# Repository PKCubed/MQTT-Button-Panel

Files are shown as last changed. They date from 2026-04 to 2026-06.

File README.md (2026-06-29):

# MQTT-Button-Panel

A panel of four, customizable, RGB-backlit buttons designed for use with Home Assistant and communication over MQTT via WiFi and Ethernet.

PXL_20260501_205123144 RAW-01 MP COVER

# Setup Steps (Work in Progress)
- Setup MQTT broker
- Add command router automation to HA
- Configure a button panel with its web interface
  - Find it's IP address by entering the menu (pressing both small buttons at the same time)
  - Set the MQTT broker IP address
  - Configure buttons with entity IDs
- Add button panel to HA
- Create automations to control systems with the button panel entities
  - Use [this blueprint](https://gist.github.com/PKCubed/5fed5823f06fd57056f4231d421e1b52) to link the button panel entities to switches

## Hardware

This design is centered around a WT32-ETH01 development board. This is an ESP32 with a LAN8720 Ethernet transceiver allowing for both WiFi and Ethernet connectivity.
On the circuit board are placed the 4 main buttons and two bank/menu buttons. Each button has a WS2812b addressable RGB led placed next to it. The front side of the board also holds the 16x2 character LCD.
The back side of the PCB holds the WT32-ETH01. To program the ESP32, the board is populated with a CP2102 USB to UART converter IC. This allows us to easily program the ESP32 with the USB C connection.
To interface with the character LCD and buttons, two PCF8574 I2C IO expanders are placed on the board. One of which is used for the character LCD while the other is used to read input from the 6 buttons.

## 3D Printed Case

Click [here](/cad/README.md) for detailed 3D printing instructions.

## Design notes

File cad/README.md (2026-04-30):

# Printing Instructions

## Buttons



* ### Transparent Part

PXL_20260430_143414308 RAW-01 MP COVER

\
Set infill to solid (100% density) and choose a pattern you like. Concentric infill gives a nice transparency. Choosing the largest layer height seems to give the best transparency. Below are the settings I used:
| Setting | Value |
| :--- | :--- |
| Layer height | 0.28mm |
| Wall loops | 1 |
| Top surface pattern | Concentric |
| Bottom surface pattern | Concentric |
| Internal solid infill pattern | Concentric |
| Infill pattern | Concentric |
| Infill density | 100% |

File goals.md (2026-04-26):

# Functional Requirements Specification: Church Automation Button Panel

## 1. Project Overview
This document outlines the functional goals and operational requirements for a network-connected button panel, designed primarily for church lighting and systems automation. The panel serves as an interactive MQTT client, sending commands to Home Assistant, which acts as the central automation hub. Key features include dynamic button mapping via "fader-style" banks, capacitive touch previewing, RGB status indication, seamless network failover, and comprehensive web-based configuration.

## 2. Hardware Overview
* **Processing & Connectivity:** WT32-ETH01 (Provides both Ethernet and Wi-Fi capabilities).
* **Programming Interface:** Custom PCB featuring a CP2102 for USB-C programming and debugging.
* **Display:** 16x2 Character LCD for local feedback and menus.
* **Physical Controls:** * 4x Main Action Buttons.
    * 2x Bank Control Buttons (Up / Down).
* **Sensory Inputs:** 6x capacitive touch rings (one surrounding each physical button).
* **Visual Indicators:** 6x Addressable RGB LEDs located beneath each button.

## 3. Functional Requirements

### 3.1. Bank and Button Management
* **Bank Shifting:** The panel must support multiple "banks" of button layouts, similar to a digital mixing console. The Bank Up and Bank Down buttons shift the logical assignment of the 4 main physical buttons to a new set of functions.
* **Configurable Button Types:** Each logical button (e.g., Button 2 on Bank 3) must be individually configurable to behave as:
    * `Toggle / On-Off`: Alternates between two states per press.
    * `Momentary`: Active only while physically held down.
    * `Radio / Scene`: Pressing the button activates it and deactivates any other buttons assigned to the same "radio group."
* **State Synchronization:** The panel must track the state of each button locally to control its LED, while simultaneously listening for external state changes broadcasted via MQTT (ensuring two-way sync with Home Assistant).

### 3.2. Capacitive Touch "Preview" Mode
* **Touch to Preview:** Touching the capacitive ring around any button *without physically depressing it* must trigger a preview action.
* **Display Feedback:** Upon touch detection, the 16x2 LCD must immediately display the configured name and intended function of that specific button.
* **Auto-Revert:** When the user removes their finger from the capacitive ring, the LCD must automatically revert to its default idle view.

### 3.3. LCD Display Behavior
* **Idle State:** * Top Line: Displays the custom Panel Name or the currently active Bank Name.
    * Bottom Line: Displays network status, active IP address, or a general system summary.
* **Preview State (During Touch):**
    * Top Line: "Button: [Assigned Button Name]"
    * Bottom Line: "Action: [Assigned Function/Current State]"
* **Menu State:** Displays navigable settings when the local menu is activated (see Section 3.7).

### 3.4. LED Status Management
* **State Indication:** The RGB LED beneath each button reflects its current state.
* **Customization:** The colors for "ON" and "OFF" states must be user-configurable per button via the Web UI. The system defaults to Green for ON and Red for OFF.
* **Bank Transition Feedback:** The LEDs under the Bank Up/Down buttons should provide visual feedback (e.g., a brief flash) to confirm a successful bank change, or indicate if the user has reached the highest/lowest available bank.

### 3.5. Network Connectivity and Failover
* **Primary Link:** Hardwired Ethernet.
* **Secondary Link:** Wi-Fi.
* **Automatic Failover:** The system must actively monitor the Ethernet connection. If the physical link drops or the connection to the MQTT broker is lost, the panel must seamlessly and automatically switch to the pre-configured Wi-Fi network to maintain functionality.
* **IP Management:** The panel must support both DHCP (default) and Static IP addressing.

### 3.6. MQTT Integration
* **Standardized Communication:** All actions and state changes are communicated to the Home Assistant broker via MQTT.
* **Configurable Topics:** Base topic structures and individual button labels must be entirely customizable via the Web UI to fit the user's existing Home Assistant naming conventions.
* **Standardized Payloads:** The panel should use standard, easily parseable payloads (e.g., simple strings like "ON", "OFF" or basic JSON).

### 3.7. Local Device Menu
* **Activation:** The user can access a local configuration menu directly on the panel by pressing and holding both the Bank Up and Bank Down buttons simultaneously.
* **Navigation:** The Bank Up/Down buttons are used to scroll through menu items, while specific main buttons act as "Select" and "Back/Exit".
* **Menu Capabilities:**
    * **Network Diagnostics:** View active interface (ETH vs. Wi-Fi), IP Address, and MAC Address.
    * **IP Configuration:** Toggle between DHCP and Static IP modes, and manually alter a static IP address directly from the panel.
    * **System Control:** Trigger a device reboot or initiate a full factory reset.

### 3.8. Web Configuration Interface
* **Accessibility:** The panel must host a local web server accessible via standard web browsers.
* **Global Settings:** Configure Panel Name, Max Number of Banks, and MQTT Broker details (IP, Port, Username, Password).
* **Network Settings:** Input Wi-Fi credentials and define IP configurations.
* **Button Matrix Setup:** A comprehensive interface to define the behavior for every button on every bank. This includes:
    * The Button's Display Name (for the LCD).
    * The specific MQTT label/topic.
    * The Button Type (Toggle, Momentary, Scene Group).
    * Custom RGB HEX codes for ON and OFF states.
* **Persistence:** All settings configured in the web interface must be saved securely to non-volatile memory so they survive reboots and power cycles.

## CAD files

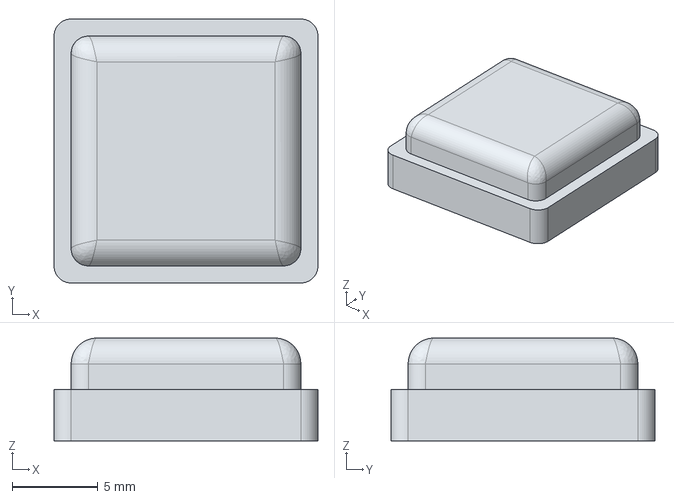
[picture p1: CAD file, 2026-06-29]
cad/Small Button.step
15.4 x 15.4 x 6.00 mm

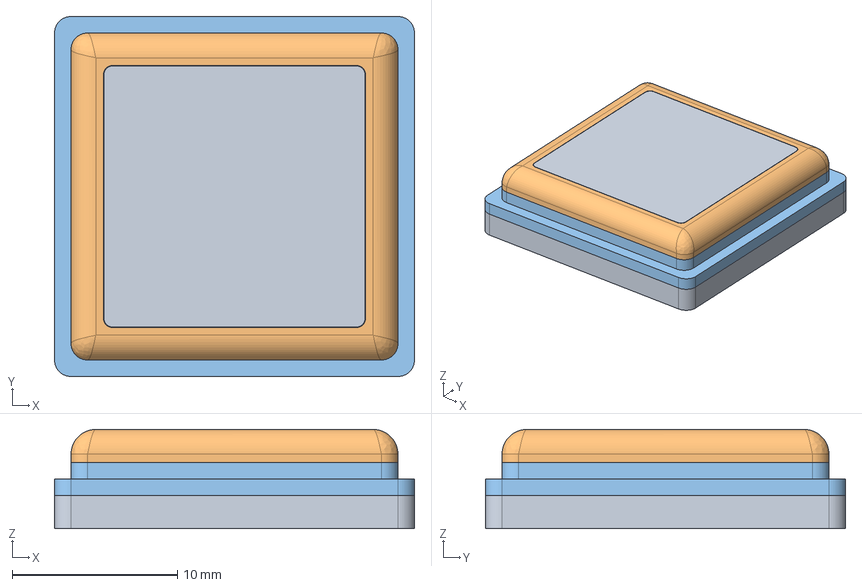
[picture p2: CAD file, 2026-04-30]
cad/4-Button Panel Buttons.FCStd
21.8 x 21.8 x 6.00 mm
Large Transparent
Large-Touch
Large Black

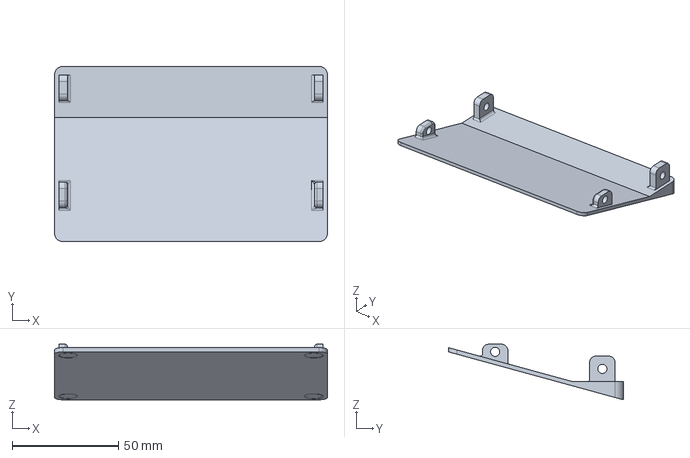
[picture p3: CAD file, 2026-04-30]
cad/4-Button Panel Case v1.3.FCStd
128.4 x 82.4 x 26.2 mm

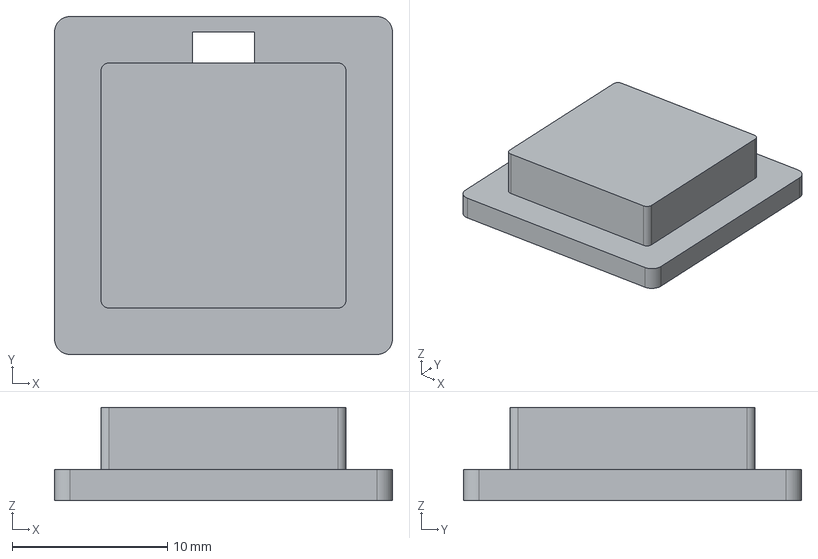
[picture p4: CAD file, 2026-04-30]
cad/Large Button (Transparent).step
21.8 x 21.8 x 6.00 mm

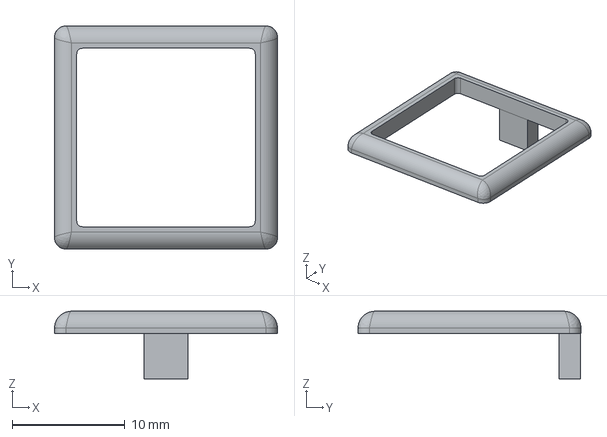
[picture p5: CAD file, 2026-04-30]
cad/Large Button (Conductive).step
19.8 x 19.8 x 6.00 mm

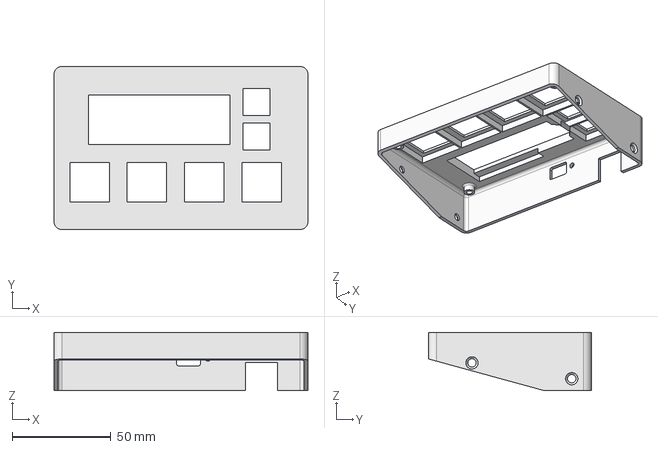
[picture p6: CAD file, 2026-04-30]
cad/Case Front v1.3.step
128.4 x 82.4 x 29.4 mm

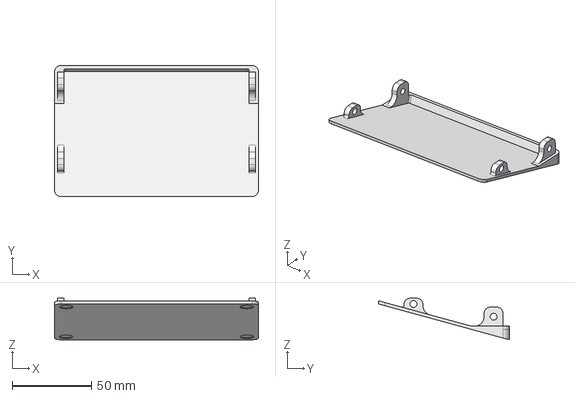
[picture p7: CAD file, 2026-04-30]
cad/Case Back v1.3.step
128.4 x 82.4 x 26.2 mm

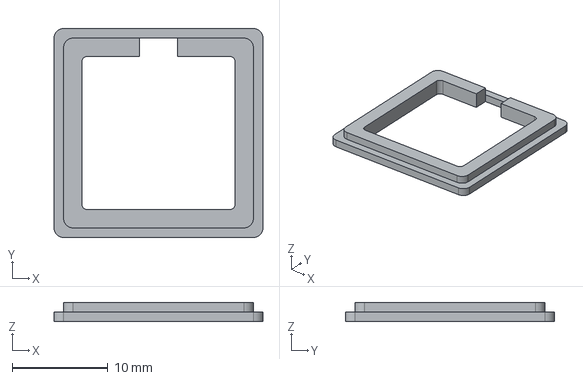
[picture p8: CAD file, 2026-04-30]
cad/Large Button (Black).step
21.8 x 21.8 x 2.00 mm

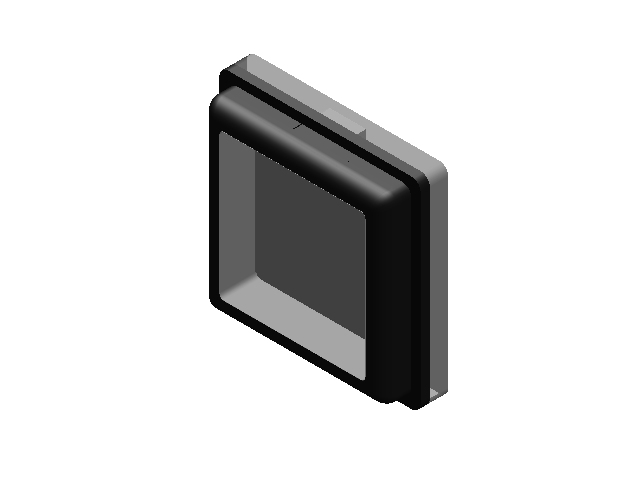
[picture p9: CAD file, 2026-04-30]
cad/Large Button.SLDASM
Large Button (Black)
Large Button (Conductive)
Large Button (Transparent)

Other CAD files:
cad/Case Back v1.3.3MF
cad/Case Back v1.3.SLDPRT
cad/Case Front v1.3.3MF
cad/Case Front v1.3.SLDPRT
cad/Large Button (Black).SLDPRT
cad/Large Button (Conductive).SLDPRT
cad/Large Button (Transparent).SLDPRT

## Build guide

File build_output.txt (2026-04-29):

Processing wt32-eth01 (platform: espressif32; board: wt32-eth01; framework: espidf)
--------------------------------------------------------------------------------
Verbose mode can be enabled via `-v, --verbose` option
CONFIGURATION: https://docs.platformio.org/page/boards/espressif32/wt32-eth01.html
PLATFORM: Espressif 32 (6.11.0) > Wireless-Tag WT32-ETH01 Ethernet Module
HARDWARE: ESP32 240MHz, 320KB RAM, 4MB Flash
DEBUG: Current (cmsis-dap) External (cmsis-dap, esp-bridge, esp-prog, iot-bus-jtag, jlink, minimodule, olimex-arm-usb-ocd, olimex-arm-usb-ocd-h, olimex-arm-usb-tiny-h, olimex-jtag-tiny, tumpa)
PACKAGES: 
 - framework-espidf @ 3.50401.0 (5.4.1) 
 - tool-cmake @ 3.16.4 
 - tool-esp-rom-elfs @ 0.0.1+20241011 
 - tool-esptoolpy @ 1.40501.0 (4.5.1) 
 - tool-idf @ 1.0.1 
 - tool-mconf @ 1.4060000.20190628 (406.0.0) 
 - tool-ninja @ 1.9.0 
 - tool-riscv32-esp-elf-gdb @ 11.2.0+20220823 
 - tool-xtensa-esp-elf-gdb @ 11.2.0+20230208 
 - toolchain-esp32ulp @ 1.23800.240113 (2.38.0) 
 - toolchain-xtensa-esp-elf @ 14.2.0+20241119
Reading CMake configuration...
LDF: Library Dependency Finder -> https://bit.ly/configure-pio-ldf
LDF Modes: Finder ~ chain, Compatibility ~ soft
Found 0 compatible libraries
Scanning dependencies...
No dependencies
Building in release mode
Linking .pio\build\wt32-eth01\firmware.elf
Retrieving maximum program size .pio\build\wt32-eth01\firmware.elf
Checking size .pio\build\wt32-eth01\firmware.elf
Advanced Memory Usage is available via "PlatformIO Home > Project Inspect"
RAM:   [=         ]  13.0% (used 42624 bytes from 327680 bytes)
Flash: [===       ]  26.3% (used 1067400 bytes from 4063232 bytes)
Building .pio\build\wt32-eth01\firmware.bin
esptool.py v4.5.1
Creating esp32 image...
Merged 2 ELF sections
Successfully created esp32 image.
========================= [SUCCESS] Took 12.99 seconds =========================

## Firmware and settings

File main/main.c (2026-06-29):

#include <stdio.h>
#include <string.h>
#include <ctype.h>

#include "driver/gpio.h"
#include "driver/i2c.h"
#include "driver/rmt.h"
#include "driver/touch_pad.h"
#include "esp_eth.h"
#include "esp_wifi.h"
#include "esp_event.h"
#include "esp_log.h"
#include "esp_netif.h"
#include "esp_netif_defaults.h"
#include "esp_timer.h"
#include "freertos/FreeRTOS.h"
#include "freertos/task.h"
#include "freertos/queue.h"
#include "freertos/semphr.h"
#include "nvs_flash.h"

#include "esp_http_server.h"
#include "nvs.h"
#include "cJSON.h"
#include "web_assets.h"

#include "mqtt_client.h"
#include "esp_system.h"
static esp_mqtt_client_handle_t s_mqtt_client = NULL;

#define ARRAY_LEN(x) (sizeof(x) / sizeof((x)[0]))
static const char *TAG = "panel_main";

/* -------------------------------------------------------------------------- */
/* Hardware mapping                                                           */
/*                                                                            */
/* These values describe the board wiring. Keeping them centralized makes it  */
/* easier to change hardware without chasing pin numbers through the rest of  */
/* the code.                                                                  */
/* -------------------------------------------------------------------------- */
#define ETH_PHY_ADDR 1
#define ETH_PHY_RST_GPIO -1
#define ETH_MDC_GPIO 23
#define ETH_MDIO_GPIO 18
#define ETH_PHY_POWER_GPIO 16

#define I2C_PORT I2C_NUM_0
#define I2C_SDA GPIO_NUM_14
#define I2C_SCL GPIO_NUM_5
#define I2C_FREQ_HZ 100000

#define PCF_LCD_ADDR 0x27
#define PCF_BUTTON_ADDR 0x26

#define LCD_PIN_EN 0x04
#define LCD_PIN_RW 0x02
#define LCD_PIN_RS 0x01
#define LCD_PIN_BL 0x08

#define BUTTON_COUNT 6
static const uint8_t k_button_pcf_bits[BUTTON_COUNT] = {5, 4, 3, 2, 1, 0};

static const touch_pad_t k_touch_channels[BUTTON_COUNT] = {
    TOUCH_PAD_NUM0, TOUCH_PAD_NUM3, TOUCH_PAD_NUM2, 
    TOUCH_PAD_NUM5, TOUCH_PAD_NUM9, TOUCH_PAD_NUM8,
};

#define LED_COUNT 6
#define LED_PIN GPIO_NUM_17
#define WS2812_RMT_CHANNEL RMT_CHANNEL_0
#define WS2812_RMT_CLK_DIV 2
#define WS2812_T0H_TICKS 14
#define WS2812_T0L_TICKS 32
#define WS2812_T1H_TICKS 28
#define WS2812_T1L_TICKS 24
#define WS2812_RESET_TICKS 2400

/* -------------------------------------------------------------------------- */
/* Panel configuration model                                                  */
/*                                                                            */
/* The runtime UI is driven by a small in-memory description of the panel:    */
/* banks, buttons, MQTT topics, and LED colors.                               */
/* -------------------------------------------------------------------------- */
#define MAX_BANKS 8
#define MAIN_BTN_COUNT 4
#define BTN_BANK_DOWN 4
#define BTN_BANK_UP 5
#define CONFIG_FORMAT_VERSION 2

typedef enum { BTN_TYPE_TOGGLE, BTN_TYPE_MOMENTARY, BTN_TYPE_RADIO } btn_type_t;

typedef struct {
    char display_name[17];
    char entity_id[64];
    btn_type_t type;
    uint8_t color_on[3];  // RGB
    uint8_t color_off[3]; // RGB
    uint8_t radio_group;  // 0 means no group
} button_config_t;

typedef struct {
    char bank_name[17];
    button_config_t buttons[MAIN_BTN_COUNT];
} bank_config_t;

typedef struct {
    char panel_name[17];
    uint8_t num_banks;
    bank_config_t banks[MAX_BANKS];
} system_config_t;

typedef struct {
    char broker_ip[32];
    char port[8];      // Kept as string for easier HTML form parsing
    char username[32];
    char password[64];
} mqtt_config_t;

typedef struct {
    char ssid[33];           // WiFi SSID (max 32 chars)
    char password[64];       // WiFi password
    bool use_dhcp;           // true = DHCP, false = static IP
    char static_ip[16];      // Static IP address (e.g., "192.168.1.50")
    char static_netmask[16]; // Netmask (e.g., "255.255.255.0")
    char static_gateway[16]; // Gateway (e.g., "192.168.1.1")
} app_wifi_config_t;

/* Default MQTT settings are loaded into RAM first, then overwritten from     */
/* NVS if the user has already saved values from the web UI.                  */
static mqtt_config_t s_mqtt_config = {
    .broker_ip = "192.168.1.100",
    .port = "1883",
    .username = "",
    .password = ""
};

/* Default WiFi settings */
static app_wifi_config_t s_wifi_config = {
    .ssid = "YOUR_SSID",
    .password = "YOUR_PASS",
    .use_dhcp = true,
    .static_ip = "192.168.1.100",
    .static_netmask = "255.255.255.0",
    .static_gateway = "192.168.1.1"
};

/* -------------------------------------------------------------------------- */
/* Runtime state                                                              */
/*                                                                            */
/* These globals are intentionally split between persistent configuration     */
/* and live state. The hardware task only reports changes; the logic task      */
/* decides what those changes mean for the UI and MQTT state.                 */
/* -------------------------------------------------------------------------- */
static system_config_t s_config;
static uint8_t s_current_bank = 0;
static bool s_btn_states[MAX_BANKS][MAIN_BTN_COUNT] = {false}; // Logical states (ON/OFF)
static bool s_in_menu = false;
static int s_menu_index = 0;
static const char *s_menu_items[] = { "Active IP", "MQTT Broker IP", "System Uptime" };
static const int s_menu_items_count = sizeof(s_menu_items) / sizeof(s_menu_items[0]);
static bool s_in_submenu = false;
static char s_active_ip[16] = "0.0.0.0";
static int64_t s_boot_time_ms = 0;
static int64_t s_mqtt_connect_time_ms = 0;
static bool s_mqtt_connected = false;
/* Startup animation keeps running until boot is fully complete.              */
static bool s_startup_complete = false;
static bool s_bank_btns_held[2] = {false, false};
static bool s_ignore_bank_release[2] = {false, false};

/* Connection flags let the UI decide whether to show online/offline cues     */
/* without needing to query the networking stack repeatedly.                  */
static bool s_eth_connected = false;
static bool s_wifi_connected = false;

/* Input events are funneled through a queue so the tasks stay decoupled.     */
static QueueHandle_t s_btn_event_queue;

typedef enum { EVT_BTN_PRESSED, EVT_BTN_RELEASED, EVT_TOUCH_START, EVT_TOUCH_END, EVT_MQTT_SYNC } event_type_t;
typedef struct {
    event_type_t type;
    uint8_t btn_idx;
} input_event_t;


/* RMT frame buffer used to encode one WS2812 LED update.                     */
static rmt_item32_t s_led_items[(LED_COUNT * 24) + 1];
static bool s_eth_link = false;
static bool s_eth_has_ip = false;

/* Touch sensing is based on a baseline captured at boot.                    */
static uint16_t s_touch_baseline[BUTTON_COUNT] = {0};
static bool s_touch_ready = false;

static uint8_t s_button_state = 0xFF;
static uint8_t s_button_last_state = 0xFF;
static int64_t s_button_last_change_ms[BUTTON_COUNT] = {0};

/* Cache the last LCD output so we can avoid sending unchanged text over I2C. */
static char s_lcd_last_line1[17] = {0};
static char s_lcd_last_line2[17] = {0};
static SemaphoreHandle_t s_i2c_mutex = NULL;
static SemaphoreHandle_t s_lcd_mutex = NULL;

/* Keep configuration within safe bounds even if NVS data is old/corrupt. */
static void sanitize_config(void)
{
    if (s_config.num_banks < 1 || s_config.num_banks > MAX_BANKS) {
        s_config.num_banks = 1;
    }

    s_config.panel_name[sizeof(s_config.panel_name) - 1] = '\0';

    for (int b = 0; b < MAX_BANKS; ++b) {
        s_config.banks[b].bank_name[sizeof(s_config.banks[b].bank_name) - 1] = '\0';
        for (int i = 0; i < MAIN_BTN_COUNT; ++i) {
            button_config_t *btn = &s_config.banks[b].buttons[i];
            btn->display_name[sizeof(btn->display_name) - 1] = '\0';
            btn->entity_id[sizeof(btn->entity_id) - 1] = '\0';
            size_t topic_len = strnlen(btn->entity_id, sizeof(btn->entity_id));
            while (topic_len > 0) {
                unsigned char last = (unsigned char)btn->entity_id[topic_len - 1];
                if (last != '/' && !isspace(last)) {
                    break;
                }
                btn->entity_id[topic_len - 1] = '\0';
                topic_len--;
            }
            if (btn->type < BTN_TYPE_TOGGLE || btn->type > BTN_TYPE_RADIO) {
                btn->type = BTN_TYPE_TOGGLE;
            }
        }
    }

    if (s_current_bank >= s_config.num_banks) {
        s_current_bank = 0;
    }
}

/* Queue-based redraw helper. MQTT callbacks run outside the logic task, so   */
/* they request a refresh indirectly instead of touching UI state directly.   */
static void request_ui_refresh(void)
{
    if (s_btn_event_queue != NULL) {
        input_event_t sync_evt = {
            .type = EVT_MQTT_SYNC,
            .btn_idx = 0xFF,
        };
        xQueueSend(s_btn_event_queue, &sync_evt, 0);
    }
}


/* Keep all timing math in milliseconds for readability.                     */
static int64_t now_ms(void)
{
    return esp_timer_get_time() / 1000;
}

static void build_mqtt_topic(char *dst, size_t dst_size, const char *base_topic, const char *suffix)
{
    if (dst_size == 0) {
        return;
    }

    dst[0] = '\0';

    if (!base_topic || !suffix) {
        return;
    }

    size_t base_len = strnlen(base_topic, dst_size - 1);
    while (base_len > 0) {
        unsigned char last = (unsigned char)base_topic[base_len - 1];
        if (last != '/' && !isspace(last)) {
            break;
        }
        base_len--;
    }

    if (base_len == 0) {
        return;
    }

    snprintf(dst, dst_size, "%.*s/%s", (int)base_len, base_topic, suffix);
}

static void build_panel_mqtt_topic(char *dst, size_t dst_size, const char *entity_id, const char *suffix)
{
    if (dst_size == 0) {
        return;
    }

    dst[0] = '\0';

    if (!entity_id || !suffix) {
        return;
    }

    char base_topic[96];
    if (strncmp(entity_id, "panels/", 7) == 0) {
        snprintf(base_topic, sizeof(base_topic), "%s", entity_id);
    } else if (strncmp(entity_id, "panels-", 7) == 0) {
        snprintf(base_topic, sizeof(base_topic), "panels/%s", entity_id + 7);
    } else {
        snprintf(base_topic, sizeof(base_topic), "panels/%s", entity_id);
    }

    build_mqtt_topic(dst, dst_size, base_topic, suffix);
}

static void sanitize_discovery_id(char *dst, size_t dst_size, const char *src, const char *fallback)
{
    if (dst_size == 0) {
        return;
    }

    dst[0] = '\0';
    size_t out = 0;

    if (src != NULL) {
        for (size_t i = 0; src[i] != '\0' && out < dst_size - 1; ++i) {
            unsigned char ch = (unsigned char)src[i];
            if (isalnum(ch)) {
                dst[out++] = (char)tolower(ch);
            } else if (ch == '/' || ch == '-' || ch == ' ' || ch == '.') {
                dst[out++] = '_';
            } else if (ch == '_') {
                dst[out++] = '_';
            }
        }
    }

    if (out == 0 && fallback != NULL) {
        for (size_t i = 0; fallback[i] != '\0' && out < dst_size - 1; ++i) {
            unsigned char ch = (unsigned char)fallback[i];
            if (isalnum(ch)) {
                dst[out++] = (char)tolower(ch);
            } else if (ch == '/' || ch == '-' || ch == ' ' || ch == '.') {
                dst[out++] = '_';
            }
        }
    }

    dst[out] = '\0';
}

static void publish_button_discovery(uint8_t bank, uint8_t btn)
{
    if (!s_mqtt_client || !s_mqtt_connected) {
        return;
    }

    char legacy_device_id[48];
    sanitize_discovery_id(legacy_device_id, sizeof(legacy_device_id), s_config.panel_name, "mqtt_button_panel");
    if (legacy_device_id[0] == '\0') {
        snprintf(legacy_device_id, sizeof(legacy_device_id), "%s", "mqtt_button_panel");
    }

    char legacy_object_id[96];
    char legacy_discovery_topic[256];
    snprintf(legacy_object_id, sizeof(legacy_object_id), "%s_bank_%02u_button_%02u", legacy_device_id, (unsigned)(bank + 1), (unsigned)(btn + 1));
    snprintf(legacy_discovery_topic, sizeof(legacy_discovery_topic), "homeassistant/switch/%s/%s/config", legacy_device_id, legacy_object_id);

    esp_mqtt_client_publish(s_mqtt_client, legacy_discovery_topic, "", 0, 1, 1);

    char topic_id[96];
    char unique_id[192];
    char discovery_topic[256];

    const button_config_t *cfg = &s_config.banks[bank].buttons[btn];
    if (bank >= s_config.num_banks || cfg->entity_id[0] == '\0') {
        return;
    }

    sanitize_discovery_id(topic_id, sizeof(topic_id), cfg->entity_id, "button");
    if (topic_id[0] == '\0') {
        return;
    }

    snprintf(unique_id, sizeof(unique_id), "%s", topic_id);
    snprintf(discovery_topic, sizeof(discovery_topic), "homeassistant/switch/%s/config", topic_id);

     char state_topic[96];
     char command_topic[96];
     char ui_command_topic[96];
     build_panel_mqtt_topic(state_topic, sizeof(state_topic), cfg->entity_id, "state");
     build_panel_mqtt_topic(command_topic, sizeof(command_topic), cfg->entity_id, "command");
     /* Advertise a harmless UI command topic so Home Assistant accepts the discovery
         but ensure it won't be used by panels or the automation. This prevents HA
         from publishing to the real "command" topic that panels use. */
     build_panel_mqtt_topic(ui_command_topic, sizeof(ui_command_topic), cfg->entity_id, "ui_command");

    cJSON *root = cJSON_CreateObject();
    if (!root) {
        return;
    }

     cJSON_AddStringToObject(root, "name", cfg->display_name[0] ? cfg->display_name : topic_id);
     cJSON_AddStringToObject(root, "unique_id", unique_id);
     cJSON_AddStringToObject(root, "object_id", topic_id);
     /* Advertise a UI command topic that HA will publish to when toggled in the
         UI. Panels and the automation ignore this topic; the automation listens
         only to the canonical "command" topic published by panels. */
     //cJSON_AddStringToObject(root, "command_topic", ui_command_topic);
     cJSON_AddStringToObject(root, "command_topic", state_topic);
     cJSON_AddStringToObject(root, "state_topic", state_topic);
     cJSON_AddStringToObject(root, "payload_on", "ON");
     cJSON_AddStringToObject(root, "payload_off", "OFF");

    char *payload = cJSON_PrintUnformatted(root);
    if (payload != NULL) {
        esp_mqtt_client_publish(s_mqtt_client, discovery_topic, payload, 0, 1, 1);
        ESP_LOGI(TAG, "MQTT DISCOVERY: %s", discovery_topic);
        cJSON_free(payload);
    }

    cJSON_Delete(root);
}

static void clear_button_discovery_by_entity_id(const char *entity_id)
{
    if (!s_mqtt_client || !s_mqtt_connected || entity_id == NULL || entity_id[0] == '\0') {
        return;
    }

    char topic_id[96];
    char discovery_topic[256];
    sanitize_discovery_id(topic_id, sizeof(topic_id), entity_id, "button");
    if (topic_id[0] == '\0') {
        return;
    }

    snprintf(discovery_topic, sizeof(discovery_topic), "homeassistant/switch/%s/config", topic_id);
    esp_mqtt_client_publish(s_mqtt_client, discovery_topic, "", 0, 1, 1);
    ESP_LOGI(TAG, "MQTT DISCOVERY CLEAR: %s", discovery_topic);
}

static void publish_mqtt_discovery(void)
{
    if (!s_mqtt_client || !s_mqtt_connected) {
        return;
    }

    for (uint8_t b = 0; b < MAX_BANKS; ++b) {
        for (uint8_t i = 0; i < MAIN_BTN_COUNT; ++i) {
            publish_button_discovery(b, i);
        }
    }
}

static void subscribe_all_state_topics(const system_config_t *cfg)
{
    if (!s_mqtt_client || cfg == NULL) {
        return;
    }

    for (int b = 0; b < cfg->num_banks; b++) {
        for (int i = 0; i < MAIN_BTN_COUNT; i++) {
            char sub_topic[80];
            build_panel_mqtt_topic(sub_topic, sizeof(sub_topic), cfg->banks[b].buttons[i].entity_id, "state");
            esp_mqtt_client_subscribe(s_mqtt_client, sub_topic, 1);
            ESP_LOGI(TAG, "Subscribed to: %s", sub_topic);
        }
    }
}
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
void app_main(void)
{
    s_boot_time_ms = now_ms();
    // 1. Initialize NVS (Required for Wi-Fi and later web settings)
    esp_err_t ret = nvs_flash_init();
    if (ret == ESP_ERR_NVS_NO_FREE_PAGES || ret == ESP_ERR_NVS_NEW_VERSION_FOUND) {
      ESP_ERROR_CHECK(nvs_flash_erase());
      ret = nvs_flash_init();
    }
    ESP_ERROR_CHECK(ret);

    load_default_config();
    load_settings_nvs(); // Saved settings override the baked-in defaults.
    load_full_config_nvs(); // Load any saved full system config

    s_btn_event_queue = xQueueCreate(20, sizeof(input_event_t));

    ESP_ERROR_CHECK(esp_netif_init());
    ESP_ERROR_CHECK(esp_event_loop_create_default());

    // 2. Initialize Hardware
    // Bring up peripherals before networking so the splash screen can appear
    // immediately while the transport stack is still starting.
    i2c_init();       
    lcd_init();
    buttons_init();
    touch_init_all();
    ws2812_init();

    s_startup_complete = false;
    // The startup task keeps animating in the background until boot completes.
    xTaskCreate(startup_task, "startup_ui", 3072, NULL, 6, NULL);
    
    // 3. Initialize Network Failover
    init_network_failover();

    // 4. Create Tasks
    xTaskCreate(hardware_task, "hw_poll", 4096, NULL, 5, NULL);
    
    // 5. Start Web Server
    start_webserver();

    s_startup_complete = true;

    xTaskCreate(logic_task, "app_logic", 4096, NULL, 4, NULL);
    
    update_system_ui(-1);

    ESP_LOGI(TAG, "System Boot Complete. Tasks running.");
}

/* Persist the entire system configuration (system + mqtt + wifi) as blobs in NVS. */
static void save_full_config_nvs(void)
{
    nvs_handle_t my_handle;
    if (nvs_open("storage", NVS_READWRITE, &my_handle) == ESP_OK) {
        uint32_t cfg_version = CONFIG_FORMAT_VERSION;
        nvs_set_u32(my_handle, "cfg_ver", cfg_version);
        nvs_set_blob(my_handle, "sys_cfg", &s_config, sizeof(s_config));
        nvs_set_blob(my_handle, "mqtt_cfg", &s_mqtt_config, sizeof(s_mqtt_config));
        nvs_set_blob(my_handle, "wifi_cfg", &s_wifi_config, sizeof(s_wifi_config));
        nvs_commit(my_handle);
        nvs_close(my_handle);
        ESP_LOGI(TAG, "Full config saved to NVS");
    }
}

static void load_full_config_nvs(void)
{
    nvs_handle_t my_handle;
    if (nvs_open("storage", NVS_READONLY, &my_handle) == ESP_OK) {
        uint32_t cfg_version = 0;
        if (nvs_get_u32(my_handle, "cfg_ver", &cfg_version) != ESP_OK) {
            cfg_version = 0;
        }

        size_t required_size = 0;
        if (nvs_get_blob(my_handle, "sys_cfg", NULL, &required_size) == ESP_OK && required_size == sizeof(s_config)) {
            nvs_get_blob(my_handle, "sys_cfg", &s_config, &required_size);
            ESP_LOGI(TAG, "Loaded system config from NVS");
        }

        required_size = 0;
        if (nvs_get_blob(my_handle, "mqtt_cfg", NULL, &required_size) == ESP_OK && required_size == sizeof(s_mqtt_config)) {
            nvs_get_blob(my_handle, "mqtt_cfg", &s_mqtt_config, &required_size);
            ESP_LOGI(TAG, "Loaded mqtt config from NVS");
        }

        required_size = 0;
        if (nvs_get_blob(my_handle, "wifi_cfg", NULL, &required_size) == ESP_OK && required_size == sizeof(s_wifi_config)) {
            nvs_get_blob(my_handle, "wifi_cfg", &s_wifi_config, &required_size);
            ESP_LOGI(TAG, "Loaded wifi config from NVS");
        }
        nvs_close(my_handle);

        if (cfg_version < CONFIG_FORMAT_VERSION) {
            migrate_grb_colors_to_rgb();
            save_full_config_nvs();
            ESP_LOGI(TAG, "Migrated LED colors to RGB config format");
        }
    }

    sanitize_config();
}

/* Apply WiFi configuration changes immediately (reconnect with new settings) */
static void apply_wifi_config(void)
{
    // Disconnect first
    esp_wifi_disconnect();
    
    // Create ESP WiFi config struct from app settings
    wifi_config_t esp_wifi_cfg = {
        .sta = {
            .threshold.authmode = WIFI_AUTH_WPA2_PSK,
        },
    };
    strncpy((char*)esp_wifi_cfg.sta.ssid, s_wifi_config.ssid, sizeof(esp_wifi_cfg.sta.ssid) - 1);
    strncpy((char*)esp_wifi_cfg.sta.password, s_wifi_config.password, sizeof(esp_wifi_cfg.sta.password) - 1);
    
    // Set WiFi config
    ESP_ERROR_CHECK(esp_wifi_set_config(WIFI_IF_STA, &esp_wifi_cfg));
    
    // Apply IP settings via netif
    esp_netif_t *netif = esp_netif_get_handle_from_ifkey("WIFI_STA_DEF");
    if (netif) {
        if (s_wifi_config.use_dhcp) {
            esp_netif_dhcpc_stop(netif);
            esp_netif_dhcpc_start(netif);
            ESP_LOGI(TAG, "WiFi: DHCP enabled");
        } else {
            esp_netif_dhcpc_stop(netif);
            esp_netif_ip_info_t ip_info;
            esp_netif_str_to_ip4(s_wifi_config.static_ip, &ip_info.ip);
            esp_netif_str_to_ip4(s_wifi_config.static_netmask, &ip_info.netmask);
            esp_netif_str_to_ip4(s_wifi_config.static_gateway, &ip_info.gw);
            esp_netif_set_ip_info(netif, &ip_info);
            ESP_LOGI(TAG, "WiFi: Static IP %s set", s_wifi_config.static_ip);
        }
    }
    
    // Reconnect
    esp_wifi_connect();
    ESP_LOGI(TAG, "WiFi reconnecting with new config: %s", s_wifi_config.ssid);
}

/* Reboot the device */
static esp_err_t api_reboot_handler(httpd_req_t *req)
{
    ESP_LOGI(TAG, "Reboot requested via web API");
    httpd_resp_set_type(req, "application/json");
    httpd_resp_send(req, "{\"result\":\"rebooting\"}", HTTPD_RESP_USE_STRLEN);
    
    // Schedule reboot in 500ms to ensure response is sent
    vTaskDelay(pdMS_TO_TICKS(500));
    esp_restart();
    return ESP_OK;
}

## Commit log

2026-04-26 Add functional requirements specification for button panel
2026-04-28 Added comments and menu button color when pressed
2026-04-28 Web UI Button Customization
    [partitions.csv]
2026-04-28 Improved Button/Bank Config + MQTT server based functionality
    The web interface was improved with copy/paste and import export for button configurations
    In addition, the buttons now function differently. Instead of immediately changing the local button state when a button is pressed, the data is first sent to home assistant via MQTT where an automati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
2026-04-28 Updated firmware
    It may be possible that when the MQTT topics are changed, the new topics are not subscribed to, and a reboot is required. This should be fixed if it is indeed a problem.
    [main.c]
2026-04-29 Much better MQTT HA integration, bug-fixes
    [main.c]
2026-04-30 Fixed MQTT button feedback bug
    Removed the /command updates in the HA MQTT auto discover configuration json. This prevents HA from ending up in a feedback loop specifically with radio buttons.
    [main.c]
2026-04-30 Added initial 3D CAD files
    [4-Button Panel Buttons.FCStd, 4-Button Panel Case v1.3.FCStd, Case Back v1.3.3MF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]
2026-04-30 Create README.md with printing instructions
    Added detailed printing instructions for transparent parts.
2026-04-30 Update README with printing instructions and images
    Added images and details to the printing instructions section.
2026-04-30 Enhance README with hardware specifications
    Added hardware details about the WT32-ETH01 board and components used.
2026-05-01 Update README with image and hardware details
    Added an image and expanded hardware description for the MQTT Button Panel.
2026-06-29 Created Small Button.step
    [Small Button.step]
2026-06-29 Add setup steps to README
    Added setup steps for configuring the button panel with Home Assistant and MQTT.
